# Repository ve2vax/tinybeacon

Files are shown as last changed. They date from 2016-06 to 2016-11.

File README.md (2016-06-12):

# TinyBeacon Project -- VHF/UHF radio beacon

*Work in progress -- rev.C*

This code was written for a set of radio beacons, usable on VHF and UHF radio-amateur bands. This firmware drives the components using SPI/I2C ports and manage the sequencer. Beacons can transmit WSPR and PI4 protocols (digital modes) but any other mode usable on class C could be used.
Schematic and PCB layout will be ported on CircuitMaker, and release soon (ref. Rev.D). Previous version helped to improve the design and 4 beacons are now used successfully on air (Montreal, Canada - FN35).
Schematic & PCB designs are offered for 50, 144, 222 & 432 MHz, using a credit card size format. The Output power is 5W (QRP) and the device tolerate an input power supply between 10 and 15V @1.5A max. Finally, the PLL is disciplined by GPS to provide an exact frequency carrier and allows WSPR mode.

<h2>Keywords:</h2>
radio beacon, vhf, uhf, wspr, pi4, qrp, gpsdo

<h3>Basically, this application :</h3>
- Configure the GPS output clock, and configure the PLL
- Encode WSPR, PI4 and CW messages
- Start sequencer:
  - Perform a time alignment, using GPS data
  - Send PI4 message (include MGM, CW, tone), duration 1 minute
  - Send PI4 message (include MGM, CW, tone), duration 1 minute
  - Send WSPR message, duration 2 minute
  - Loop...

<h2>Hardware features:</h2>
- VHF/UHF Beacon (design available for 50, 144, 220 & 440 MHz)
- Compact design / Credit card size
- 10 MHz oscillator stabilized by GPS (GPSDO)
- QRP, 5W output power
- DC-DC Power supply within 10-15V, 1.5A max

<h2>Firmware feature:</h2>
- Support WSPR & PI4 protocols
- Run on a common ATMEGA328p (like Arduino)
- Drive GPS (uBlox Max-8) date/time sync & GPSDO sync signal
- Drive PLL (ADF4355) for frequency adjustment

<h3>Howto:</h3>
1. Install avr-gcc & avr-dude on your Unix disto
2. Edit source code files to change your callsign, locator and frequency (morse.c pi4.c wspr.c)
3. Use "make" to build the firmware
4. Use "make burn" to flash the firmware, with a "AVR Pocket Programmer"
5. Disconnect the programming cable & cut the power supply (the programmer could interfere with SPI port)

<h2>Links for this project:</h2>
- Article : TODO
- Hardware : http://circuitmaker.com/User/Details/Guenael-VA2GKA
- Twitter : https://twitter.com/guenael_jouchet
- Blog : https://www.guenael.ca/

<h3>Notes:</h3>
- Make your first tests with a dummy load (>10W)
- Never setup an antenna with a return loss greater than -10dB / SWR 2:1
- Use a RF power-meter and an ampermeter for calibration (efficiency should be greater than 60%)
- Check thermal dissipation

<h3>TODO:</h3>
- fine frequency test -- click noise problem
- add 6 hex header validation -- gps com' part
- fix timing (email Bo)
- test Si PLL
- better PLL lib, freq calculation without reg. adjustment
- Callsign / loc / freq. in one place

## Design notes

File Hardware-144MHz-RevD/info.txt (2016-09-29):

- Surface : 80mm x 55mm (3149.606 mil x 2165.354 mil) - 4 layers, 1.6mm
- Gerber files : 4:2 Suppress leading zeroes / Metric(mm) / Reference to absolute. (Gerber & Excellon files)
- Projet filename : TinyBeacon144-RevD.zip
- Laser stencil only requiert for the top face (components face, file paste_1.GBX)
- No top overlay, no bottom Overlay, no bottom paste
- Files: 
  - layer_1.GBX : Top Side
  - layer_2.GBX : Inner Layer 1
  - layer_3.GBX : Inner Layer 2
  - layer_4.GBX : Bot Side
  - mask_1.GBX  : Top Soldermask
  - mask_4.GBX  : Bot Soldermask
  - paste_1.GBX : Top Paste
  - drills.DRL  : Drills / Excellon format
  - rout.GBX    : Rout provided as GBX - Width 2mm

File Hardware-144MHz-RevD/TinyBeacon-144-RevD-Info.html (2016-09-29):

Altium

# Board Information

Date: | | 2016-07-24
Time: | | 15:23:03
Elapsed Time: | | 00:00:18
Filename: | | TinyBeacon-144-RevD.CMPcbDoc
Units: | | mmmils

General
Horizontal Dimension, max | 82mm
Vertical Dimension, max | 57mm
Total surface area
Copper layer count | 4
Smallest electrical gap/space | 0.2mm
Smallest track width | 0.1mm
Smallest hole size | 0.3mm
Biggest hole size | 3mm
Number of plated through holes | 523
Number of plated slots | 0
Number of unplated holes | 0
Number of unplated slots | 0
Number of cutouts | 1

Back to top

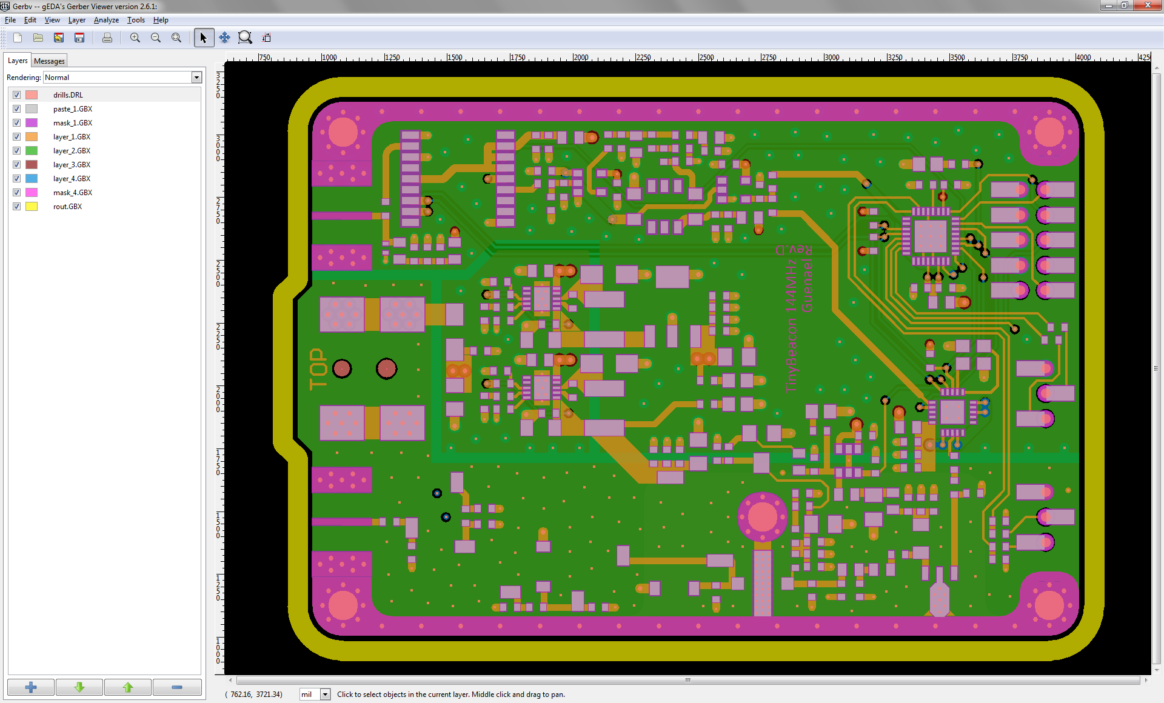
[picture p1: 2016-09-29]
Hardware-144MHz-RevD/preview.png

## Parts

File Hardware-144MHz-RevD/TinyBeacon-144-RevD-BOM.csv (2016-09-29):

Comment | Designator | Supplier Name | Supplier PN | Quantity | Footprint | Package / Case
100nF | C1, C6, C7, C14, C16, C38, C41, C44, C47, C60, C62, C63, C64, C66, C69, C70, C71 | Digikey | 490-1519-1-ND | 17 | PCB-1608 | 0603 (1608 Metric)
470nF | C2, C10 | Digikey | 490-3291-1-ND | 2 | PCB-1608 | 0603 (1608 Metric)
4.7uF | C3, C11 | Digikey | 490-9962-1-ND | 2 | PCB-2012 | 0805 (2012 Metric)
470pF | C4, C15 | Digikey | 490-1443-1-ND | 2 | PCB-1608 | 0603 (1608 Metric)
47uF | C5, C37, C39, C40 | Digikey | 478-3079-1-ND, 478-3079-1-ND, 478-3079-1-ND, 478-9009-1-ND | 4 | CAP-POL-3216 | 1206 (3216 Metric)
10nF | C8, C17, C42, C45, C48, C72 | Digikey | 490-1512-1-ND | 6 | PCB-1608 | 0603 (1608 Metric)
1nF | C9, C18, C43, C46, C49, C50, C51, C52, C61, C65, C67, C73 | Digikey | 490-1494-1-ND, 490-1494-1-ND, 490-1494-1-ND, 490-1494-1-ND, 490-1494-1-ND, 490-1494-1-ND, 490-1494-1-ND, 490-8275-1-ND, 490-1494-1-ND, 490-1494-1-ND, 490-1494-1-ND, 490-1494-1-ND | 12 | PCB-1608 | 0603 (1608 Metric)
10uF | C12 | Digikey | 399-5157-1-ND | 1 | CAP-POL-3216 | 1206 (3216 Metric)
47uF | C13, C74 | Digikey | 490-5528-1-ND | 2 | PCB-3216 | 1206 (3216 Metric)
47pF | C19, C55, C57 | Digikey | 490-1419-1-ND, 490-1343-1-ND, 490-1419-1-ND | 3 | PCB-1608 | 0603 (1608 Metric)
1500pF | C20, C23 | Digikey | 490-1455-1-ND | 2 | PCB-1608 | 0603 (1608 Metric)
100pF | C21, C22, C28, C30 | Digikey | 490-1427-1-ND | 4 | PCB-1608 | 0603 (1608 Metric)
1uF | C26 | Digikey | 490-3900-1-ND | 1 | PCB-1608 | 0603 (1608 Metric)
NC | C27 | NA | NA | 1 | PCB-2012 | 0603 (1608 Metric)
NC | C29, C35, C53, C58, C59, R18, R20, R25, R26, R40 | NA | NA | 10 | PCB-1608 | 0603 (1608 Metric)
100uF | C34 | Digikey | 490-10510-1-ND | 1 | PCB-2012 | 0805 (2012 Metric)
62pF | C54 | Digikey | 490-1346-1-ND | 1 | PCB-1608 | 0603 (1608 Metric)
15pF | C56 | Digikey | 490-13359-1-ND | 1 | PCB-1608 | 0603 (1608 Metric)
39pF | C75, C78 | Digikey | 490-1341-1-ND | 2 | PCB-1608 | 0603 (1608 Metric)
27pF | C76, C77 | Digikey | 490-1337-1-ND | 2 | PCB-1608 | 0603 (1608 Metric)
5~20pF | CV1, CV2 | Digikey | 490-7154-ND | 2 | PCB-TZC3 | Rectangular 4.50mm x 3.20mm
B220A | D1, D2, D3 | Digikey | B220A-FDICT-ND | 3 | D-SMA | SMA (DO-214AC)
TVS-SMD | D4 | Digikey | 490-9330-1-ND | 1 | PCB-1005 | 0402 (1005 Metric)
LED-GREEN | D5, D8 | Digikey | 160-1426-1-ND | 2 | PCB-LED-2012 | 0805 (2012 Metric)
LED-RED | D6 | Digikey | 160-1427-1-ND | 1 | PCB-LED-2012 | 0805 (2012 Metric)
LED-YELLOW | D7 | Digikey | 160-1428-1-ND | 1 | PCB-LED-2012 | 0805 (2012 Metric)
FIX PCB | F1, F2, F3, F4 |  |  | 4 | PCB-FIX-ROUND
FIX PA | F5 |  |  | 1 | PCB-FIX-ROUND
470R | FB1, FB2, FB3, FB4, FB5, FB6 | Digikey | 490-1039-1-ND | 6 | PCB-2012 | 0805 (2012 Metric)
CUI PJ-002AH-SMT-TR | J1 | Digikey | CP-002AHPJCT-ND | 1 | PCB-CUI-PJ-002AH-SMT | Custom
J502 Connector | J2, J3 | Digikey | J502-ND | 2 | PCB-SMA | SMA
6.8uH | L1 | Digikey | 490-11697-1-ND | 1 | PCB-5650 | 2220 (5650 Metric)
4.7uH | L2 | Digikey | 490-9760-1-ND | 1 | PCB-5650 | 2220 (5650 Metric)
27nH | L3, L8 | Digikey | AISC-0805-R027G-TCT-ND | 2 | PCB-2012 | 0805
380nH | L6 | Digikey | 535-12013-1-ND | 1 | PCB-IND-AIAC-4125 | Nonstandard (9.00mm x 4.40mm)
390nH | L7 | Digikey | 535-12422-1-ND | 1 | PCB-3216 | 1206
22nH | L9 | Digikey | 535-11990-1-ND | 1 | PCB-IND-AIAC-1812 | Nonstandard (4.70mm x 3.50)
47nH | L10, L11 | Digikey | 535-11994-1-ND | 2 | PCB-IND-AIAC-1812 | Nonstandard (4.70mm x 3.50)
Header 5x2 | P1 |  |  | 1 | PCB-HDR2X5-SMD
Header 3x1 | P2, P3 |  |  | 2 | PCB-0rhklu08i7n9dxwvdgja-1
309k | R1 | Digikey | RHM309KCFCT-ND | 1 | PCB-1608 | 0603 (1608 Metric)
18k | R2, R7 | Digikey | RHM18KCFCT-ND | 2 | PCB-1608 | 0603 (1608 Metric)
40.2k | R3, R8 | Digikey | RHM40.2KCFCT-ND | 2 | PCB-1608 | 0603 (1608 Metric)
33k | R4 | Digikey | RHM33.0KCFCT-ND | 1 | PCB-1608 | 0603 (1608 Metric)
47k | R5, R9, R22, R23, R35, R37, R39 | Digikey | RHM47.0KCFCT-ND | 7 | PCB-1608 | 0603 (1608 Metric)
180k | R6 | Digikey | RHM180KCFCT-ND | 1 | PCB-1608 | 0603 (1608 Metric)
10 | R10, R21 | Digikey | RHM10KCT-ND | 2 | PCB-2012 | 0805 (2012 Metric)
0 | R11, R14 | Digikey | RHM0.0GCT-ND | 2 | PCB-1608 | 0603 (1608 Metric)
100k | R12 | Digikey | RHM100KCFCT-ND | 1 | PCB-1608 | 0603 (1608 Metric)
1k | R13 | Digikey | RHM1.00KCFCT-ND | 1 | PCB-1608 | 0603 (1608 Metric)
10k | R15, R16, R19, R24, R27, R31, R32, R33 | Digikey | RHM10.0KCFCT-ND | 8 | PCB-1608 | 0603 (1608 Metric)
33 | R17, R30, R34 | Digikey | RHM33.0CFCT-ND | 3 | PCB-1608 | 0603 (1608 Metric)
4.7k | R28, R36, R38 | Digikey | RHM4.70KCFCT-ND | 3 | PCB-1608 | 0603 (1608 Metric)
22 | R29 | Digikey | RHM22KCT-ND | 1 | PCB-2012 | 0805 (2012 Metric)
~10k | RT1 | Digikey | 490-6944-1-ND | 1 | PCB-1608 | 0603 (1608 Metric)
0~10k | RV1 | Digikey | 490-2661-1-ND | 1 | PCB-PVG5 | Non-standard
LT3480 | U1, U2 | Digikey | LT3480EDD#PBF-ND | 2 | PCB-LT3480 | 10-VSON (3x3)
TC1262-3.3 | U3 | Digikey | TC1262-3.3VDBCT-ND | 1 | PCB-SOT-223 | SOT-223
U-Blox MAX-M8Q | U4 | u-blox | MAX-M8Q | 1 | PCB-GPS-MAX8Q | Custom
NC7SZ04 | U5 | Digikey | NC7SZ04M5XCT-ND | 1 | PCB-SOT-23-5 | SOT-23-5
VCTCXO-10M | U6 | Digikey | CW769CT-ND | 1 | PCB-TB524 | 10-QFN (Non Standard)
Si5351C | U7 | Digikey | 336-2402-ND | 1 | PCB-QFN-20 | 20-QFN (4x4)
NC7SZ86 | U8 | Digikey | NC7SZ86M5XCT-ND | 1 | PCB-SOT-23-5 | SOT-23-6
TPS22929DDBVT | U10 | Digikey | 296-30174-1-ND | 1 | PCB-SOT-23-6 | SOT-23
ATF-52189-BLK | U11 | Digikey | 516-2371-ND | 1 | PCB-SOT-89-3 | SOT-89-3
NE5550979A | U12 | Digikey | NE5550979A-A-ND | 1 | PCB-NE5550979A | Non-standard
Atmel ATMEGA328P-MU | U13 | Digikey | ATMEGA328P-MU-ND | 1 | QFN-32 | 32-VQFN (5x5)
XTAL-SMD | X1 | Digikey | 535-9679-1-ND | 1 | PCB-4SMD-32-25 | 4 SMD Custom 3.2mm x 2.5mm

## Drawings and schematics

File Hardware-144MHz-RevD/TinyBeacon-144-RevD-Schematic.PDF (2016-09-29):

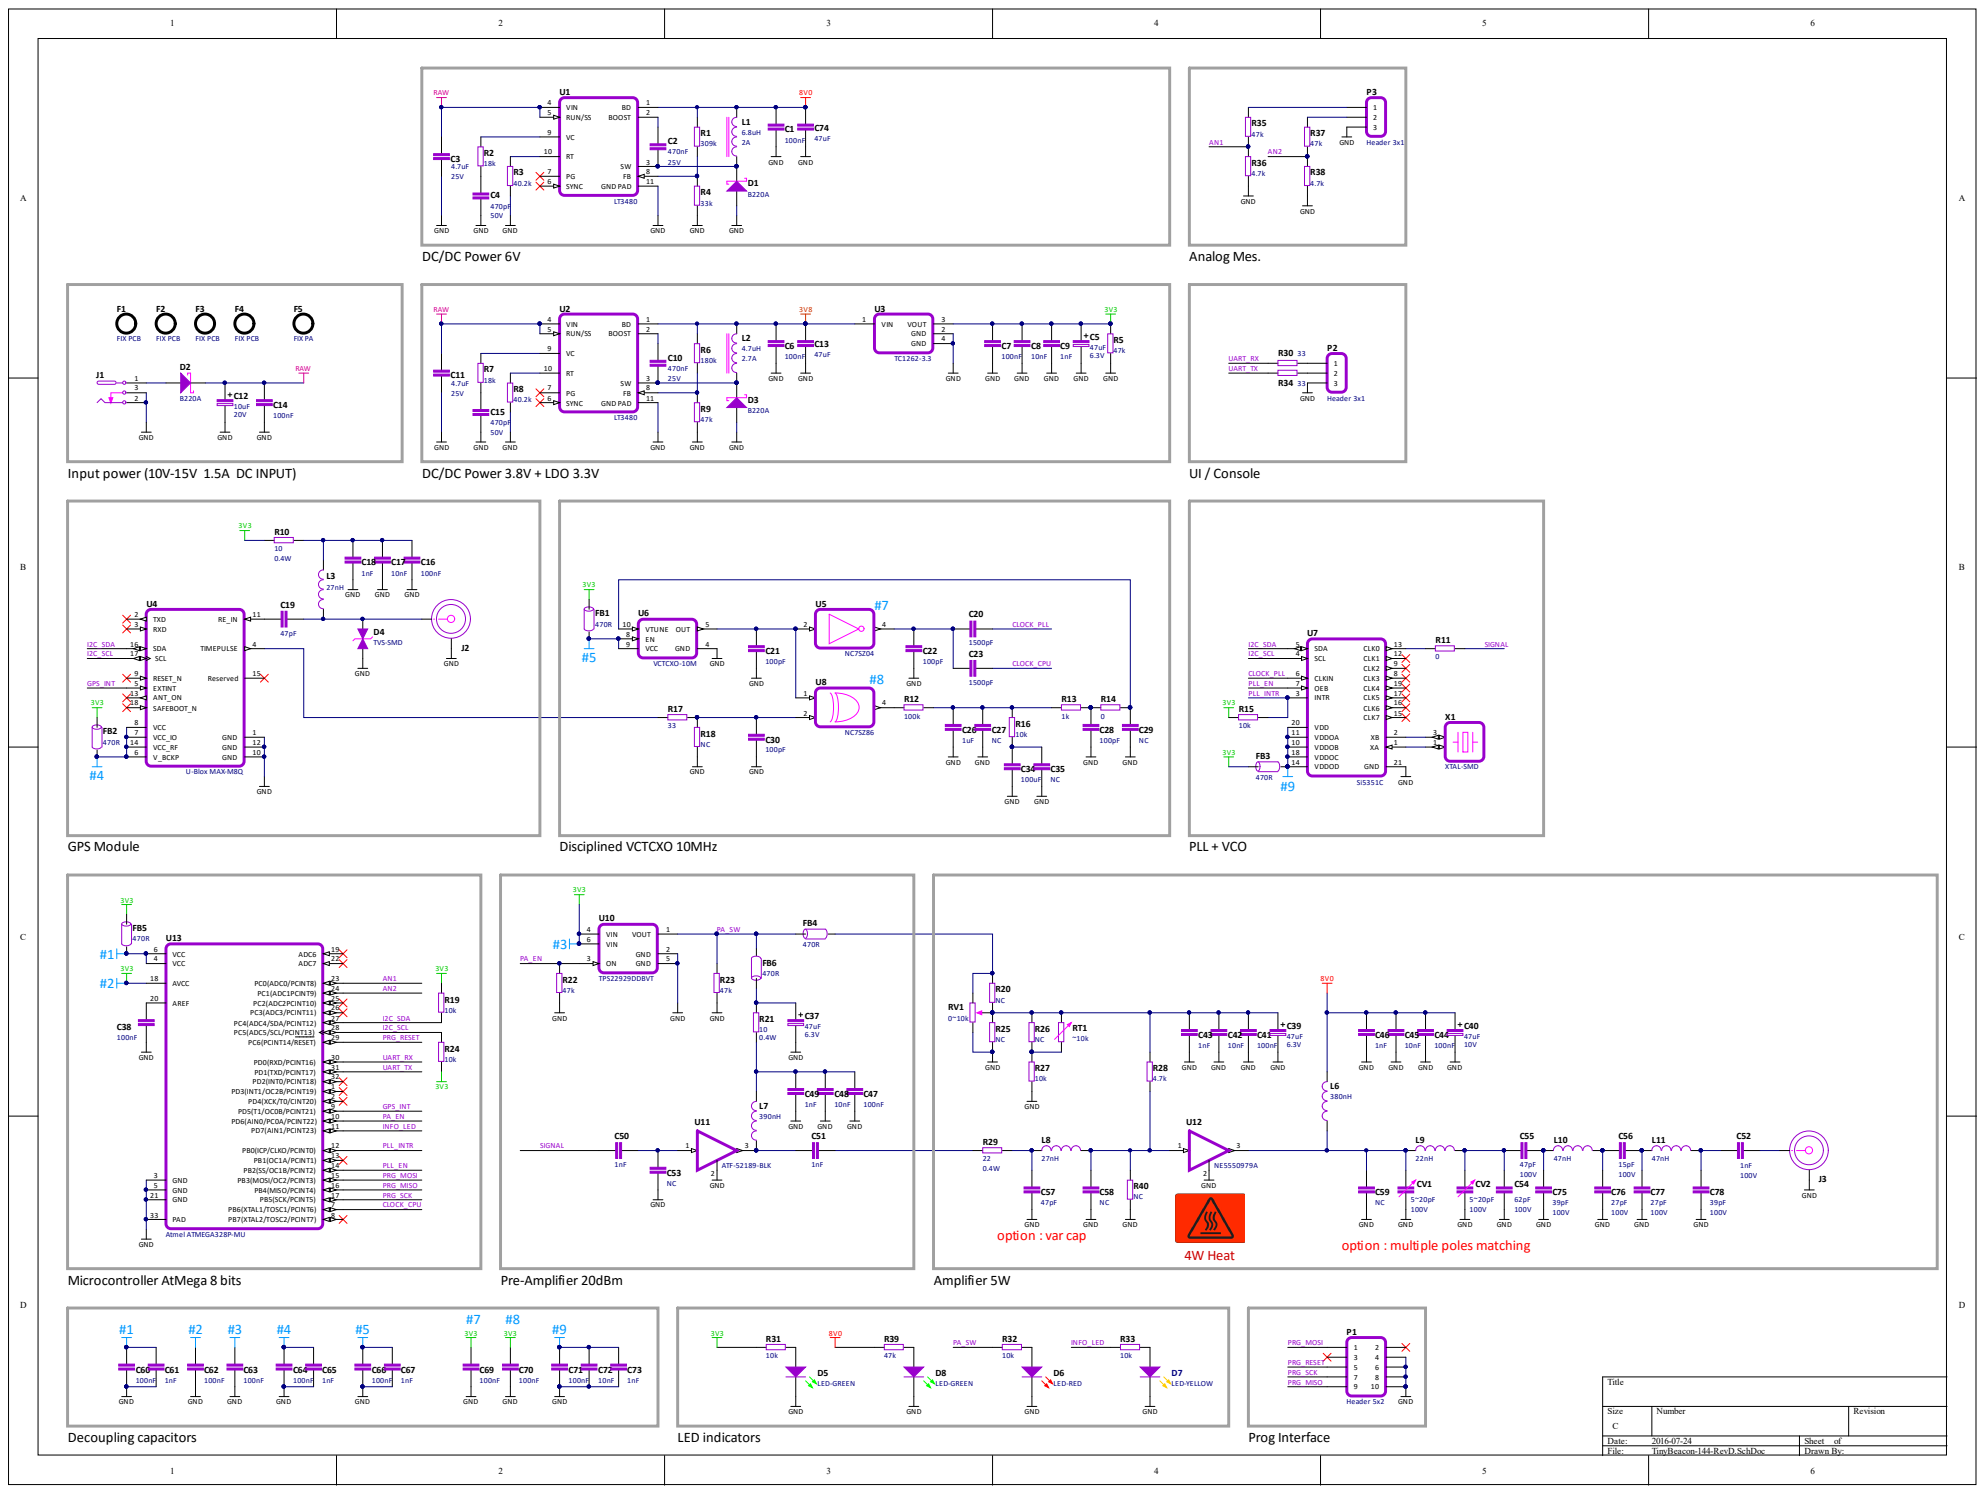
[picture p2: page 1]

option : multiple poles matching

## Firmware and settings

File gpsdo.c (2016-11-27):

/*
 * FreeBSD License
 * Copyright (c) 2016, Guenael
 * All rights reserved.
 *
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
 * THIS SOFTWARE IS PROVIDED BY THE COPYRIGHT HOLDERS AND CONTRIBUTORS "AS IS" AND
 * ANY EXPRESS OR IMPLIED WARRANTIES, INCLUDING, BUT NOT LIMITED TO, THE IMPLIED
 * WARRANTIES OF MERCHANTABILITY AND FITNESS FOR A PARTICULAR PURPOSE ARE
 * DISCLAIMED. IN NO EVENT SHALL THE COPYRIGHT OWNER OR CONTRIBUTORS BE LIABLE FOR
 * ANY DIRECT, INDIRECT, INCIDENTAL, SPECIAL, EXEMPLARY, OR CONSEQUENTIAL DAMAGES
 * (INCLUDING, BUT NOT LIMITED TO, PROCUREMENT OF SUBSTITUTE GOODS OR SERVICES;
 * LOSS OF USE, DATA, OR PROFITS; OR BUSINESS INTERRUPTION) HOWEVER CAUSED AND
 * ON ANY THEORY OF LIABILITY, WHETHER IN CONTRACT, STRICT LIABILITY, OR TORT
 * (INCLUDING NEGLIGENCE OR OTHERWISE) ARISING IN ANY WAY OUT OF THE USE OF THIS
 * SOFTWARE, EVEN IF ADVISED OF THE POSSIBILITY OF SUCH DAMAGE.
 *
 */


/* |                                                                   |
   |  TinyBeacon project                                               |
   |                                                                   |
   |  - VHF/UHF Beacon (design available for 50, 144, 220 & 440 MHz)   |
   |  - Compact design / Credit card size                              |
   |  - QRP, 5W output power                                           |
   |  - 10 MHz oscillator stabilized by GPS (GPSDO)                    |
   |  - DC-DC Power supply within 10-15V, 1.5A max                     |
   |  - Compatible with WSPR & PI4 protocols                           |
   |                                                                   |
   |                                                                   |
   |  IO Mapping uController, rev.C                                    |
   |                                                                   |
   |  - PC4/SDA  (pin 27) | I2C SDA                                    |
   |  - PC5/SCL  (pin 28) | I2C SCL                                    |
   |  - PD0/RXD  (pin 30) | USART RX                                   |
   |  - PD1/TXD  (pin 31) | USART TX                                   |
   |  - PD5      (pin  9) | GPS INT                                    |
   |  - PD6      (pin 10) | PA EN                                      |
   |  - PD7      (pin 11) | INFO LED                                   |
   |  - PB0      (pin 12) | PLL LOCK                                   |
   |  - PB2      (pin 14) | PLL EN                                     |
   |                                                                   | */

#include "config.h"

#include "twi.h"
#include "gps.h"
#include "pll.h"
#include "usart.h"

#include "morse.h"
#include "pi4.h"
#include "wspr.h"

#include <avr/io.h>
#include <avr/interrupt.h>
#include <util/delay.h>


void timeAlignPI4() {
    /* Get GPS data for the next time sync */
    gpsGetTime();

    /* Align on an minute for the next message */
    gpsTimeAling1Mb();
}


void timeAlignWSPR() {
    /* Get GPS data for the next time sync */
    gpsGetTime();

    /* Align on odd minute for the next message */
    gpsTimeAling2Mb();
}


void pi4sequence() {
    /* 1st part : Send PI4 message, 25 sec */
    pi4Send();

    /* 2nd part : Send morse message */
    morse2TonesSendMessage();

    /* 3th part : Send a carrier, 10 sec, same frequency */
    pllUpdate(1);
    pllPA(1);
    pllRfOutput(1);
    _delay_ms(10000);
    pllRfOutput(0);
    pllPA(0);
}


int main (void) {
    /* CKDIV8 fuse is set -- Frequency is divided by 8 at startup : 2.5MHz */
    cli();
    CLKPR = _BV(CLKPCE);  // Enable change of CLKPS bits
    CLKPR = 0;            // Set prescaler to 0 = Restore system clock to 10 MHz
    sei();

    /* LED : Set pin 11 of PORT-PD7 for output*/
    DDRD |= _BV(DDD7);

    /* For now, used for DEBUG purpose only. Future : CLI for freq settings & modes */
    usartInit();
    _delay_ms(10);

    /* Peform I2C modules init */
    twi_init();
    _delay_ms(10);

    /* Prepare the message to encode for PI4 message */
    pi4Encode();

    /* Prepare the message to encode for WSPR message */
    wsprEncode();

    /* uBlox : GPS IO init & Set the default I2C address of the GPS */
    gpsInit(0x42);  // I2C Have to be init before the PLL !

    /* uBlox : Rstrict DDC port only */
    gpsSet_CFG_PRT();

    /* uBlox : Wait on a full GPS sync (+ info req. for message encoding)*/
    gpsGetPVT();
    gpsExtractStrings();
    gpsGetTime();

    /* uBlox : 10MHz timing setup */
    gpsSet_CFG_TP5();

    /* uBlox : Refresh rate for internal GPSDO alignment */
    gpsSet_CFG_RATE();

    /* ADF4355 PLL Init, conf & settings */
    pllInit(0x60);  // 0x60 used only for Si5351 (I2C addr.)

    /* End of init sequence : Turn on the LED (pin 11) */
    PORTD |= _BV(PORTD7);

    /* Start with a unsync TX, boring to wait a full sync... */
    pi4Send();
    wsprSend();

    /* Loop sequence :
       - PI4 + Morse + Tone (1 minute)
       - PI4 + Morse + Tone (1 minute)
       - WSPR (2 minutes)
    */
    while(1) {
        timeAlignPI4();
        pi4sequence();

        timeAlignPI4();
        pi4sequence();

        timeAlignWSPR();
        wsprSend();
        gpsGetTime();
        delay_sleep_window();
        }
    
   

    /* This case never happens :) Useless without powermanagement... */
    return 0;
}

/* === Si5351 DEBUG 60sec (2500 x 2 x 12ms)
pllSetFreq(144430000000000,0);
pllSetFreq(144435000000000,1);
pllUpdate(0);
pllRfOutput(1);
pllPA(1);

for (uint32_t i=0; i<2500; i++) { //while(1) {
  pllUpdate(0);
  //pllRfOutput(0);
  //_delay_ms(1000);

  pllUpdate(1);
  //pllRfOutput(1);
  //_delay_ms(1000);
}

pllRfOutput(0);
pllPA(0);
*/

/* === ADF4355 DEBUG 60sec
pllSetFreq(222295000000000,0); 
pllUpdate(0);

pllRfOutput(1);
pllPA(1);
_delay_ms(667);
pllRfOutput(0);
pllPA(0);

for (uint32_t i=0; i<60000; i++) { //while(1) {
  pllUpdate(0);
}

pllRfOutput(1);
pllPA(1);
_delay_ms(667);
pllRfOutput(0);
pllPA(0);
*/

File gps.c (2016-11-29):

/*
 * FreeBSD License
 * Copyright (c) 2016, Guenael
 * All rights reserved.
 *
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
 * THIS SOFTWARE IS PROVIDED BY THE COPYRIGHT HOLDERS AND CONTRIBUTORS "AS IS" AND
 * ANY EXPRESS OR IMPLIED WARRANTIES, INCLUDING, BUT NOT LIMITED TO, THE IMPLIED
 * WARRANTIES OF MERCHANTABILITY AND FITNESS FOR A PARTICULAR PURPOSE ARE
 * DISCLAIMED. IN NO EVENT SHALL THE COPYRIGHT OWNER OR CONTRIBUTORS BE LIABLE FOR
 * ANY DIRECT, INDIRECT, INCIDENTAL, SPECIAL, EXEMPLARY, OR CONSEQUENTIAL DAMAGES
 * (INCLUDING, BUT NOT LIMITED TO, PROCUREMENT OF SUBSTITUTE GOODS OR SERVICES;
 * LOSS OF USE, DATA, OR PROFITS; OR BUSINESS INTERRUPTION) HOWEVER CAUSED AND
 * ON ANY THEORY OF LIABILITY, WHETHER IN CONTRACT, STRICT LIABILITY, OR TORT
 * (INCLUDING NEGLIGENCE OR OTHERWISE) ARISING IN ANY WAY OUT OF THE USE OF THIS
 * SOFTWARE, EVEN IF ADVISED OF THE POSSIBILITY OF SUCH DAMAGE.
 *
 */


#include "config.h"
#include "gps.h"

#include "twi.h"

#include <avr/io.h>
#include <util/delay.h>
#include <avr/pgmspace.h>

#include <stdio.h>
#include <stdlib.h>
#include <string.h>

#include "usart.h"


/* Global definition for I2C GPS address */
static uint8_t gpsAddr;


/* Local/Private structrues for this processing code */
typedef struct gpsDataStruct {
    uint32_t  itow;
    uint16_t  year;
    uint8_t   month;
    uint8_t   day;
    uint8_t   hours;
    uint8_t   minutes;
    uint8_t   seconds;
    int32_t   nano;
    int32_t   lon;     // factor 1e-7
    int32_t   lat;     // factor 1e-7
    int32_t   height;  // in mm, factor 1e-3
    int32_t   speed;   // in mm/s, factor 1e-3
    uint8_t   numsat;
    int32_t   head;    // factor 1e-5, in deg.
    uint32_t  leapsec;
} gpsData;


typedef struct gpsStringStruct {
    // Extracted / Calculated outputs
    char posLocator[7];
    char posLat[8];
    char posLatDir[2];
    char posLon[9];
    char posLonDir[2];
    char day[3];
    char hours[3];
    char minutes[3];
    char seconds[3];
    char altitude[7];
    char speed[4];
    char head[4];
    char numsat[4];
    char seq[4];
} gpsString;


/* Goblal structrues & variables declaration */
static gpsData    lGpsData;    // Structure with all raw GPS data
static gpsString  lGpsString;  // Structure with all extracted/computed GPS data
// FIXME : global def, is static req. ?


static const uint8_t PROGMEM CFG_TP5[] = {
    0xB5, 0x62,             // Header
    0x06, 0x31,             // ID
    0x20, 0x00,             // Length
    0x00,                   // tpIdx
    0x01,                   // version
    0x00, 0x00,             // reserved1
    0x00, 0x00,             // antCableDelay
    0x00, 0x00,             // rfGroupDelay
    0x01, 0x00, 0x00, 0x00, // freqPeriod = 1 Hz
    0x80, 0x96, 0x98, 0x00, // freqPeriodLock = 10MHz
    0x00, 0x00, 0x00, 0x00, // pulseLenRatio = 0% (disable)
    0x00, 0x00, 0x00, 0x80, // pulseLenRatioLock = 50%
    0x00, 0x00, 0x00, 0x00, // userConfigDelay
    0xEF, 0x08, 0x00, 0x00, // flags
    0x7E, 0x28              // CRC
};


static const uint8_t PROGMEM CFG_RATE[] = {
    //0xB5, 0x62, 0x06, 0x08, 0x06, 0x00, 0x4B, 0x00, 0x14, 0x00, 0x00, 0x00, 0x73, 0xC6 //   75ms   / 20cyc
    //0xB5, 0x62, 0x06, 0x08, 0x06, 0x00, 0x64, 0x00, 0x0A, 0x00, 0x00, 0x00, 0x82, 0x34 //  100ms   / 10cyc
    0xB5, 0x62, 0x06, 0x08, 0x06, 0x00, 0x88, 0x13, 0x01, 0x00, 0x00, 0x00, 0xB0, 0x47 //  5000ms  / 1cyc
    //0xB5, 0x62, 0x06, 0x08, 0x06, 0x00, 0x60, 0xEA, 0x01, 0x00, 0x00, 0x00, 0x5F, 0x8A //  60000ms / 1cyc
};


static const uint8_t PROGMEM CFG_PRT[] = {
    0xB5, 0x62,             // Header
    0x06, 0x00,             // ID
    0x14, 0x00,             // Length
    0x00,                   // Port ID (0 = DDC)
    0x00,                   // Reserved1
    0x00, 0x00,             // txReady (0 = Disable)
    0x84, 0x00, 0x00, 0x00, // mode // Slave address (0x42)
    0x00, 0x00, 0x00, 0x00, // reserved2
    0x01, 0x00,             // inProtoMask  (1 = in UBX only)
    0x01, 0x00,             // outProtoMask (1 = out UBX only)
    0x00, 0x00,             // flags (0 = Extended TX timeout )
    0x00, 0x00,             // reserved5
    0xA0, 0x96              // CRC
};


static const uint8_t PROGMEM NAV_PVT[] = {
    0xB5, 0x62,             // Header
    0x01, 0x07,             // ID
    0x00, 0x00,             // Length
    0x08, 0x19              // CRC
};


static const uint8_t PROGMEM NAV_TIMEGPS[] = {
    0xB5, 0x62,             // Header
    0x01, 0x20,             // ID
    0x00, 0x00,             // Length
    0x21, 0x64              // CRC
};


void gpsInit(uint8_t addr) {
    /* GPS EXTINT : set pin 9 of PORT-PD5 for output*/
    DDRD |= _BV(DDD5);

    /* GPS EXTINT down for now (energy saver feature) */
    PORTD &= ~_BV(PORTD5);

    _delay_ms(100);

    /* Define I2C address */
    gpsAddr = addr;

    /* Note : I2C bus Init is done by i2c.c */
}


void gpsShutdown() {
}


void gpsSet_CFG_TP5() {
    // No gpsCrcUpdate -- CRC Hardcoded
    twi_writeToPgm(gpsAddr, CFG_TP5, sizeof(CFG_TP5), 1, 0);
    _delay_ms(100);
}


void gpsSet_CFG_RATE() {
    twi_writeToPgm(gpsAddr, CFG_RATE, sizeof(CFG_RATE), 1, 0);
    _delay_ms(100);
}


void gpsSet_CFG_PRT() {
    twi_writeToPgm(gpsAddr, CFG_PRT, sizeof(CFG_PRT), 1, 0);
    _delay_ms(100);
}


void gpsPoll_NAV_PVT() {
    twi_writeToPgm(gpsAddr, NAV_PVT, sizeof(NAV_PVT), 1, 0);
    _delay_ms(100);
}


void gpsPoll_NAV_TIMEGPS() {
    twi_writeToPgm(gpsAddr, NAV_TIMEGPS, sizeof(NAV_TIMEGPS), 1, 0);
    _delay_ms(100);
}


void gpsCrcUpdate(uint8_t *payload, uint8_t payloadSize) {
    /* https://www.ietf.org/rfc/rfc1145.txt */
    uint8_t ck_a = 0;
    uint8_t ck_b = 0;

    for (uint8_t i=2; i<(payloadSize-2); i++) { // Skip the header for the checksum
        ck_a = ck_a + payload[i];
        ck_b = ck_b + ck_a;
    }

    payload[payloadSize-1] = ck_b;
    payload[payloadSize-2] = ck_a;
}


void gpsFlushBuffer() {
    uint16_t byteToRead;
    uint8_t  garbage;

    uint8_t  cmd = 0xFD;

    /* Point on the bytes available (Register Adressing) */
    twi_writeTo(gpsAddr, &cmd, 1, 1, 0);  // 0xFD & 0xFE for the 16 bit register
    _delay_ms(1);

    /* Read the effective buffered byte on the GPS uProcessor */
    if(!twi_readFrom(gpsAddr, (uint8_t*) &byteToRead, 2, 0))
        return;

    byteToRead = ((byteToRead>>8) | (byteToRead<<8));  // Little endian conversion

    while (byteToRead--)
        twi_readFrom(gpsAddr, &garbage, 1, 0);
}
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

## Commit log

2016-06-12 leap second fix & cleanup
    [gps.c, gpsdo.c, pll.c]
2016-06-24 fuse update
2016-07-25 add hardware schematic & pcb
    [TinyBeacon-144-RevD-BOM.csv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]
